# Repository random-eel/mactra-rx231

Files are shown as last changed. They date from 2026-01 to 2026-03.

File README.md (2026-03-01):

<p align="center">
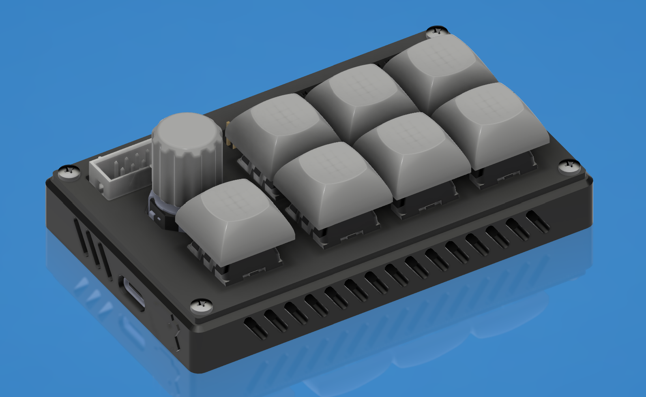
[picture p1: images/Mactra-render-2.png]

</p>  

# Mactra RX231搭載 エンコーダ付き7キーマクロパッド/開発ボード
Mactra はRenesas製RX231マイコンを搭載した、7キーマクロパッド 兼 開発ボードです。  
#### キーマップ変更は [こちらのサイト](https://random-eel.github.io/mactra-configurator/index.html)へ (要WebHID対応)  
設定ツール説明等は [こちら](https://github.com/random-eel/mactra-rx231/wiki)  
  
## 仕様・機能
 - Renesas製 RX231 マイクロコントローラ搭載 (R5F52315ADFL 48ピンQFP)
    - 32MHz 動作 (16MHz 外部発振器付き)
    - USB-C接続 (ファンクションのみ)
    - USBバスパワー動作専用
 - Kailh製MX互換スイッチホットスワップソケット x 7
   - ホットスワップなので好きな互換スイッチに入れ替え可能
   - RGB LEDバックライト付き (SK6812Mini-E Bit-bang制御)
   - 1 + 2行x3列 での接続
   - 2x3+ロータリーエンコーダ部分にダイオード有 (Col->Row)
 - RKJXT1F 4方向スイッチ付きロータリーエンコーダ x 1
 - 動作確認用オンボードLED x 2
 - GPIO/GND ピンソケット
 - 3.3v/5v ピンヘッダ
 - E2 エミュレータ用コネクタ

(ソフトウェア機能)
 - WebHIDを使用したコンフィグツール
	 - USB HIDを介したデータ転送
	 - RGB設定項目変更機能
	 - キー再配置機能
 - キー押しっぱなし機能
> [!WARNING]
> ### ⚠️ Rev.1はファームウェア書き込み時に特定のピンをショートさせる必要があります。ご注意下さい。
> Rev.2 も必要ですが、デバッグポート側にスイッチが存在し、ケーブル等で接続する必要はありません。

> [!CAUTION]
> ### ☠️ Rev.1はロータリーエンコーダの配線に致命的なミスがあり使用できません。  
> <b><u>メインボードだけRev.2の場合があります。</u></b>上記のスイッチで見分けてください。  

※~~現在ファームウェア開発中 開発状況を以下に示します。~~ 26/2/24 最低限の機能を実装したため、ファームウェア開発を完了しました。   
|開発状況|内容|説明|
|:---:|:---:|---:|
|✅️|Lチカ|背面LED点滅|
|✅️|[GPIOチェックファームの作製](https://github.com/random-eel/mactra-rx231/blob/main/firmwares/RX231-Mactra-GPIO-Test.mot)|ハンダ付けテスト用|
|✅️|[マトリクステスト](https://github.com/random-eel/mactra-rx231/blob/main/firmwares/RX231-Mactra-Matrix-Test.mot)|全キーのスキャン|
|✅️|ロータリーエンコーダ回転対応|左右回転方向等の取得|
|✅️|エンコーダ4方向スイッチ対応|上下左右のスイッチ|
|✅️|USBファンクション動作|USBデバイスとして認識|
|✅️|キーボード動作|マクロキーとして使用可能に|
|✅️|[RGB LED動作](https://github.com/random-eel/mactra-rx231/blob/main/firmwares/RX231-Mactra-SK6812Mini-E-Test.mot)|SK6812Mini-Eの点灯|
|✅️|RGB LED設定対応|キー同時押し等で変更|
|✅️|キーの設定変更対応|(ストレッチゴール)|  

## 使用方法
Mactra本体とホストデバイスをUSB-Cケーブルで接続します。  
背面のディップスイッチを操作する必要がある場合は、**必ずケーブルを抜いてから**操作して下さい。

### マクロキーとして使用する場合
**電源を切った状態**で、背面ディップスイッチを BOOT MODE: Off; USB BOOT: Off; に設定後、ケーブルを接続します。  
ファームウェアが書き込まれている場合、ケーブル接続後にマクロパッドとして動作します。  
書き込まれていない場合、下記の ***開発ボードとして使用する場合*** を参考に、ファームウェアを書き込んでください。  

初期設定のキーマップは以下の通りです。
```
(左右でボリューム)
    輝度アップ
前曲 再生/停止 次曲   [F22] [F23] [F24] 
    輝度ダウン

    [ミュート]      [Pause] [Alt+PrSc] [PrSc]
```

RGB LEDの点灯パターン・色変更等は、操作仕様が未確定なので未実装です。  
キーマップの変更は、現状ソースコードからのビルドのみとなり、未対応です。  
マルチプルエンドポイントを使用したシリアル通信で変更可能になる予定です。  

### 開発ボードとして使用する場合
<details>  
<summary>詳細</summary>  
   
基板上で<u>GPIOへのプルアップ抵抗の接続はありません</u>。  
内蔵プルアップ抵抗を利用して下さい。  
また、開発ボードとしてGPIOを使用する際には、基板上で接続されているピンも含まれているので、使用時には注意が必要です。  
基板上に接続があるピンは下記の通りです。  

|ピン|機能|説明|
|:---|---|---:|
|P14|LED|動作確認(Lチカ)用　背面|
|P16|VCC|(ブートローダモード指定用)****|
|P26|TXD|(E2デバッガ用送信)*|
|P27|RGB|RGB LED 通信用**|
|P30|RXD|(E2デバッガ用受信)*|
|P31|SW1|左下スイッチ ダイオード無し***|
|P42|RCW|ロータリーエンコーダ用 時計回り|
|P46|RCCW|ロータリーエンコーダ用 反時計回り|
|PA1|COL4|スイッチ用マトリクス 縦4|
|PA3|COL3|スイッチ用マトリクス 縦3|
|PA4|COL2|スイッチ用マトリクス 縦2|
|PA6|COL1|スイッチ用マトリクス 縦1|
|PE1|ROW3|スイッチ用マトリクス 横3|
|PE2|ROW2|スイッチ用マトリクス 横2|
|PE3|ROW1|スイッチ用マトリクス 横1|
|PE4|COL5|スイッチ用マトリクス 縦5|

\* シングルチップモード/FINED接続で使用する場合、自由に使うことが出来ます。  
** BSS138が接続されています。 常にRGB LEDに信号が流れるので、注意が必要です。  
*** スイッチはグラウンドと接続されています。  
**** USB経由でのファームウェア書き込み時に必要です。  
書き込み用スイッチ(横のスライドスイッチ)がオンのままGNDに接続しないで下さい。  

#### プログラムをUSB経由で書き込んで使う場合

> ##### ⚠️ Rev.1の場合
> スイッチを設定しても、ブートローダーモードへ起動せず、ファームウェアが書き込めません。  
> GPIO P16ピン と 3V3 ピンを接続してください。
> ##### ⚠️ Rev.2の場合
> 側面に P16-3V3 を接続するスイッチがあります。
> USB側にスライドするとOFFです。
 
<details>
<summary>詳細</summary>
 
1. **ケーブルを抜いた状態**で、背面ディップスイッチを BOOT MODE: On; USB BOOT: On; に設定後、ケーブルを接続します。  
2. Renesas Flash Programmer を使用して、ビルドしたプログラムを指定し、書き込みます。  
3. **ケーブルを抜き**、背面ディップスイッチを BOOT MODE: Off; USB BOOT: Off; に設定後、ケーブルを再接続します。
</details>

#### E2 エミュレータを使う場合(オンチップデバッギング)
<details>
<summary>詳細</summary>
 
1. **電源を切った状態**で、背面ディップスイッチを BOOT MODE: **Off**; USB BOOT: **Off**; に設定します。
2. **電源を切った状態**で、E2エミュレータとキーボードを接続します。  
3. CS+/e2studio で E2エミュレータの設定をし、接続します。 (エミュレータから電源供給可 - LED使用時は注意)
4. プログラムを実行します。  
※ E2エミュレータから電源を供給すると、5V端子の出力は無効化されます。  
※ E2エミュレータから電源を供給しても、RGB LEDにも3.3v電源が供給されます。供給電流を超えないように明るさを調整して下さい。  
</details>

> ##### ⚠️ Rev.1 & 2の場合
> GPIO P16ピン と GND ピンを接続しないでください。  
> 電源がショートし、最悪破損します。  

</details>  

## ケースについて
> [!IMPORTANT]
> 26/3/1 時点でファイルが更新されておりません。 今暫くお待ち下さい。
  
casesフォルダに3Dプリンタで出力可能なモデルを用意してあります。  
以下のネジが必要になります。何れもセルフタップになります。  
 - 3Dプリントしたケースの場合 (Type 1: 中間+キーカバー)
   - M2 15mmネジ x 4
 - 3Dプリントしたケースの場合 (Type 2: 中間のみ)
    - M2 5mmネジ x 8
 - ケース無しで使う場合 (GPIO使用時には注意)
    - M2 5mmネジ x 8
    - M2 10mm スタンドオフ x4
  
## ソースコードについて (TBD)
Renesas製のサンプルコード及びFITモジュールを使用しているため、公開可能かどうか不明です。(もう少し調べます...)  
  
御連絡頂ければソースコードをお送り致しますが、最低でもルネサスのアカウントを取得してください。    
(使用したコード・モジュール全てが、ルネサスのアカウントさえあればダウンロード可能な為)  
  
> [!WARNING]
> #### ⚠️ AI生成コードについて
> このキーボードのファームウェア開発にはGeminiを使用し生成したコードが含まれています。ご了承下さい。  
> 自作/生成したコードのみで動作するファームウェアが完成した場合、確認後にすべてのソースコードを公開する予定です。  
  
## 使用したアプリ・参考にしたサイト・サンプルコード等
* KiCAD 9.0.6
* Autodesk Fusion 360
* [Keyboard Layout Editor](https://www.keyboard-layout-editor.com/)
* [ai03 Plate Generator](https://kbplate.ai03.com/)
* [秋月電子 RX621マイコンボード 参考資料(回路図)](https://akizukidenshi.com/catalog/g/g105763/)
* [RSK-RX231 RX231 CPU Board Schematics](https://www.renesas.com/ja/design-resources/boards-kits/rsk-rx231)  
* [RX230, RX231 ハンドブック](https://www.renesas.com/ja/products/rx231)
* [RX230グループ、RX231グループ　ユーザーズマニュアル　ハードウェア編](https://www.renesas.com/ja/products/rx231)
* [RXファミリ ハードウェアデザインガイド](https://www.renesas.com/ja/products/microcontrollers-microprocessors/rx-32-bit-performance-efficiency-mcus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)
* [メインクロック回路、サブクロック回路のデザインガイド](https://www.renesas.com/ja/products/microcontrollers-microprocessors/rx-32-bit-performance-efficiency-mcus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)
* [Hardware design with RP2040](https://www.raspberrypi.com/documentation/microcontrollers/pico-series.html#documentation)
* [USB.org HID Usage Descrptions](https://usb.org/sites/default/files/hut1_21.pdf)
* RX Family Sample Program using USB Host Human Interface Device Class Driver (HHID) to communicate via USB with HID device Firmware Integration Technology Rev.1.30 - Sample Code (r01an2294)
* [tmk_keyboard](https://github.com/tmk/tmk_keyboard)
* [TinyUSB](https://github.com/hathach/tinyusb)
* [dsa-keycap](https://github.com/anhthang/dsa-keycap)
* ポリテクセンターの講義・資料
* Google Gemini

## FAQ
### 動作しない
電源LEDが点灯しない場合は、故障だと思われます。  
点灯していても動作しない場合は、ディップスイッチの設定を確認して下さい。  
ファームウェアが書き込まれていない可能性もありますので、RFSを使用して書き込んで下さい。  
開発ボードとして使用している場合、動作させているコードに問題がある可能性があります。(in short: you suck at coding)  
### RGB LEDの設定を変更したい
ロータリーエンコーダを押し込みながらSW1(ロータリーエンコーダ下スイッチ)を押すと、設定変更モードになります。  
上下で設定項目の変更、回転で数値を変更します。    
LEDが黄色の状態で左右を入力すると、LEDの点灯モードが変更できます。
|色|機能|
|---|---|
|黄|輝度変更|
|赤緑青|色彩変更|
|赤緑青/白|色彩2変更|
|紫|(未実装)|
|水|LED更新速度|
  
### スマホからキーマップ変更出来ない  
現状WebHIDのサポートが無いようです。(Android/iPhone)  
設定変更にはPCを使用して下さい。  
### キーボードのリセットを行いたい
ロータリーエンコーダを押し込みながらSW1(ロータリーエンコーダ下スイッチ)を押したまま、USBケーブルを繋げて下さい。  
それでもリセットされない場合、エンコーダ押し込み+上部のキー全てを押しながら、ケーブルを繋げて下さい。  
### 基板から注文したい
手動でのはんだ付けが幾つか必要になります。某◯月電子からMCU・ピンヘッダ・ソケット等の購入で価格を抑えられます。  
RKJXT1Fは、AliExpressから購入すると良いかもしれません。  
PCBAをするならJLCPCBをおすすめします。代替・未実装の部品を指定すると価格を抑えられます。 (not affiliated!)  
スイッチ・キーキャップ含め 5枚で2万円程になると思います。(25/1/16)  
### なぜ製作に至ったのか 
職業訓練校で使い方を学んだRXシリーズを使用して、自身のスキルを試し、能力を証明してみたかった点が一番の理由です。  
RXシリーズの開発ボードを勉強目的で安価に手に入れたかったのですが、普通の物では面白くないと思い、制作に至りました。
  
## 免責事項
このデバイス 及び ファームウェアを使用していて、誤字が増えた、ホストデバイスが壊れた、核戦争が起きた、デバイスが正しく動作しなかったせいで会社をクビになった等があっても、設計/製作者は一切の責任を負いません。  
  
## その他
 
<details>
  <summary>読まなくてもいい詳細</summary>
  
<details>
  <summary>本当に読むんですか？ (どうでもいい事しか書いてないです) </summary>

<details>
  <summary>本当の本当に読むんですか？ (実質知り合い向けな上、色々と遠慮しておりません) </summary>

<details>
  <summary>本当の本当の本当に読むんですか？ (NOT WORTH READING THIS (mostly), YOU HAVE BEEN WARNED) </summary>
  
### なんてよむの  
"[マクトラ](https://www.google.com/search?q=mactra)" です。~~このバカ貝め~~
### QMKは?
MCUのサポートが無いので無理です。どなたかがChibiOSを移植して貰えれば出来るんじゃないですかね？  
### 他のファームウェアは？
( ◠‿◠ ) 回路図あるんだから自分で用意しろ！  
### 他のMCUで作る予定は？
( ◠‿◠ ) 無い。（多分… ルネサスのチップを載せたくなったら作ります）  
### でも他のMCUの方が安いし楽なのでは?
RXシリーズの勉強用なので、それでは意味が無かったんです。  
### 勉強に使える開発ボードにしてはBYTEでアクセスしづらくない？  
安く手に入るチップがこれだったので仕方がありませんでした。  
もし次にルネサス製のチップを使うならRAにします。  
### 設定用データのパケットの内容は？
設定ツールを見て下さい。(そのうち説明は追加します)  
### 回路図は？  
~~そのうち追加予定です。~~ 26/1/26: 追加しました。[docs/mactra-schematics-rev2.pdf](https://github.com/random-eel/mactra-rx231/blob/main/docs/mactra-schematics-rev2.pdf) 
### 基板データは？
いずれ追加予定です。（Rev.2も思った通りの動作ではない為未定ですが、近日追加します)   
### BOMは？
同梱予定です。少量の位置確認が必要だと思われます。  
スイッチソケット・ダイオードアレイ・TVSダイオード・USBコネクタの位置確認が必要です。  
### アナログ入出力ヤバいんだけど  
ルネサスのデザインリファレンス通りでは無いのであしからず。おまけだと思ってもらえると。  
### LED邪魔  
電源LEDなら諦めて下さい。(自分で抵抗入れ替えるか外せば消えます)  
P14のLEDは光らないはずです。RGBバックライトはオフに出来るようにします。  
### テストファームの使い方は？
手ハンダでMCUを実装したときに、正しくハンダされているかのチェックに有用です。  
GPIO全て(P14除く)がプルアップ抵抗有効の入力ピン設定になります。  
全てのGPIOに順番に GPIOn-GND のように接続し、背面LEDが点灯することを確認して下さい。  
### なんでRev.1/2はショートが必要？
P16ピンが5V/3.3V/HIGHでなければ、USBブートモードへ移行しないようです。  
P35はVCCとの接続がありますが、どうやらブートローダのモード設定には使えないようです。ぴえん。  
使用にはあまり問題は無いと思われます(ファームウェアではP35がUSB0_VBUS設定)が、留意して使用して下さい。 
### 普通にP16潰せば良いのでは？
RIICの割り当てがあります。
### Rev.2スイッチ切ってもP16使えないんだけど？
(説明TBD) 配線もしくはスイッチの選択をミスったようです。オフの状態でも多少電流が流れてしまっているようです。  
スイッチのグラウンド不良の可能性がありますが、不明です。(シールド実測で0.3v程 スイッチのNCを真に受けた為?)  
### 配線汚いし間違ってるとかアホ？
( ◠‿◠ ) うるせえ 初心者なんだよ 誰もが通る道なんだよ
### AI使うとか雑魚？
雑魚です。正直かなり助かりました。特にUSB周りはヘルプ無しでは無理だったと思います。  
### FAQ舐めてんの？
仲間・友人程度しか見ないだろうと踏んでおります。  
あくまで勉強のための趣味の品だと思って頂けると幸いです。  
こんな素人の作品に本気になってどーすんのｗ   
### 設計者は何奴？
よくわからん少しキーボード好きの人間です。普段はRP2040で制作しています。どうでもいいですが求職中です。(26/3/1)
</details>
</details>
</details>
</details>

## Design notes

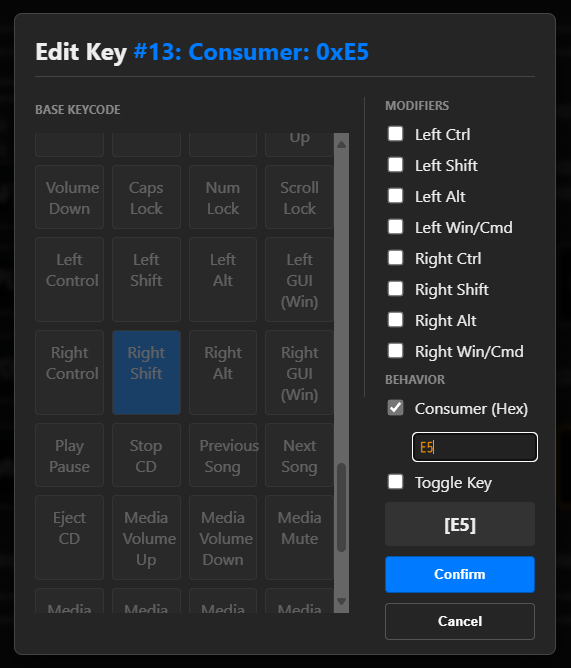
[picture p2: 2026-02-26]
images/customizer-image-consumer-0.png

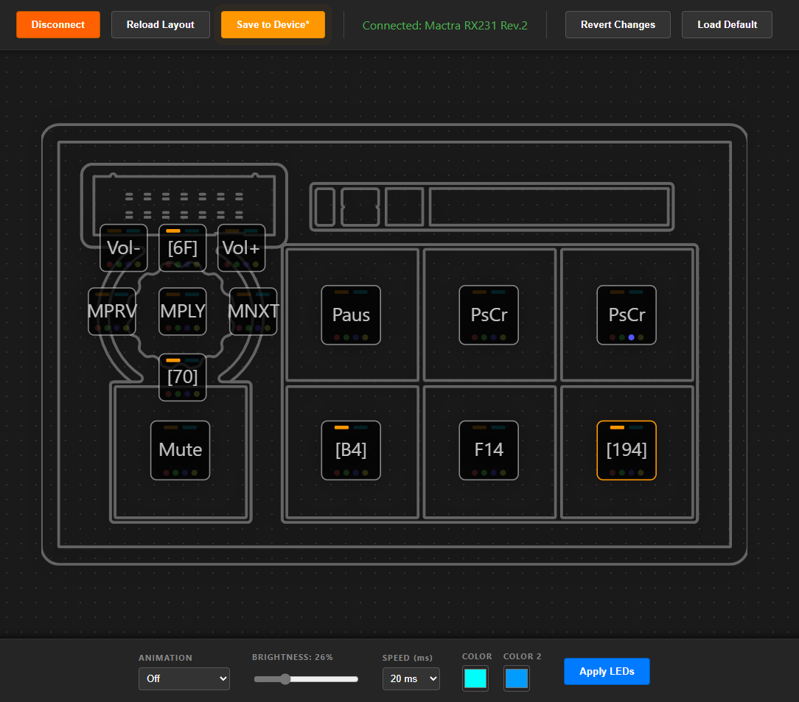
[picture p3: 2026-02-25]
images/customizer-image-0.png

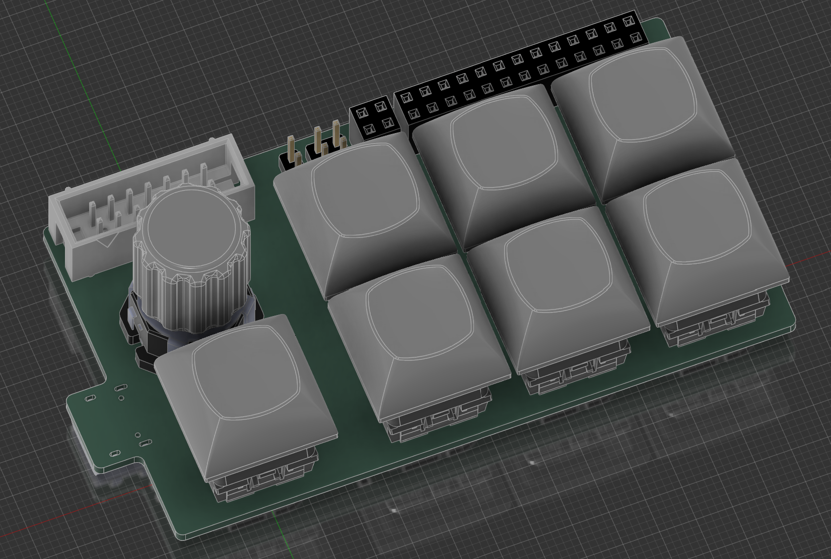
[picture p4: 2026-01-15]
images/mactra_preview.png

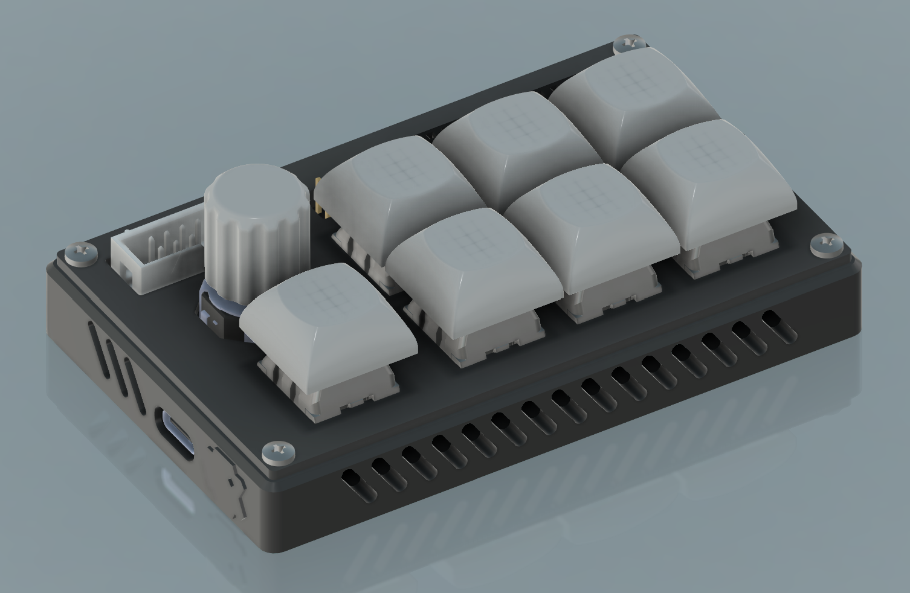
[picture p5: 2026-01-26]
images/Mactra-render.png

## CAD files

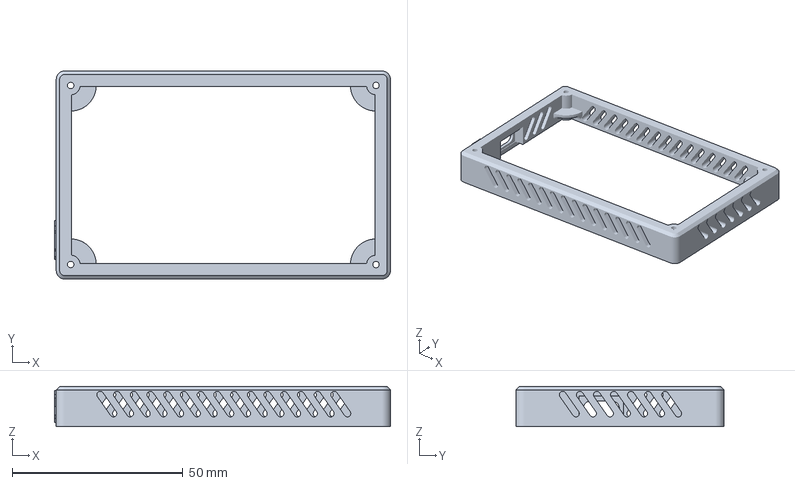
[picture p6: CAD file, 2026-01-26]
cases/Mactra-R1-Skelton-NoTop.3mf
98.5 x 61.0 x 11.8 mm

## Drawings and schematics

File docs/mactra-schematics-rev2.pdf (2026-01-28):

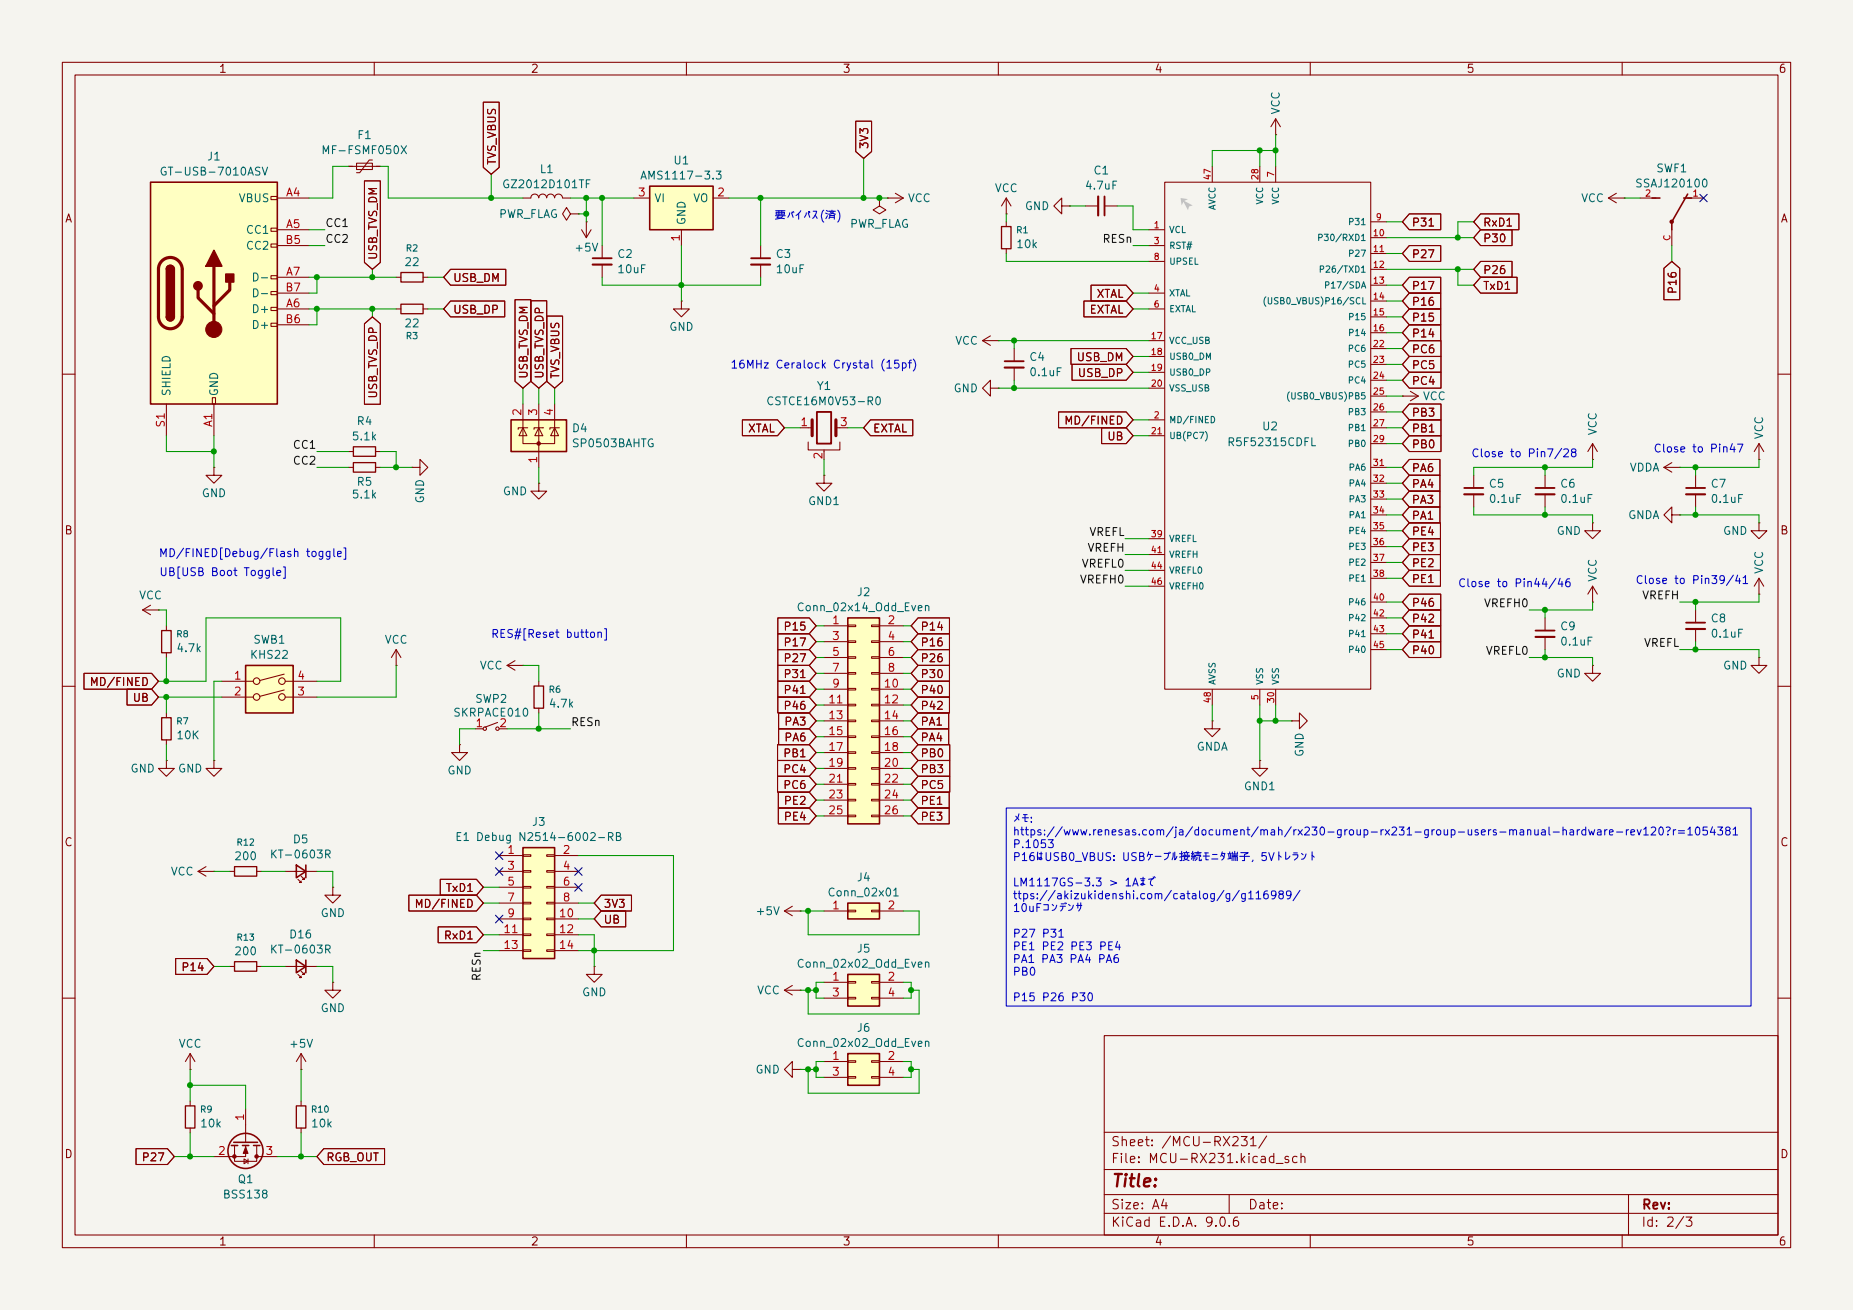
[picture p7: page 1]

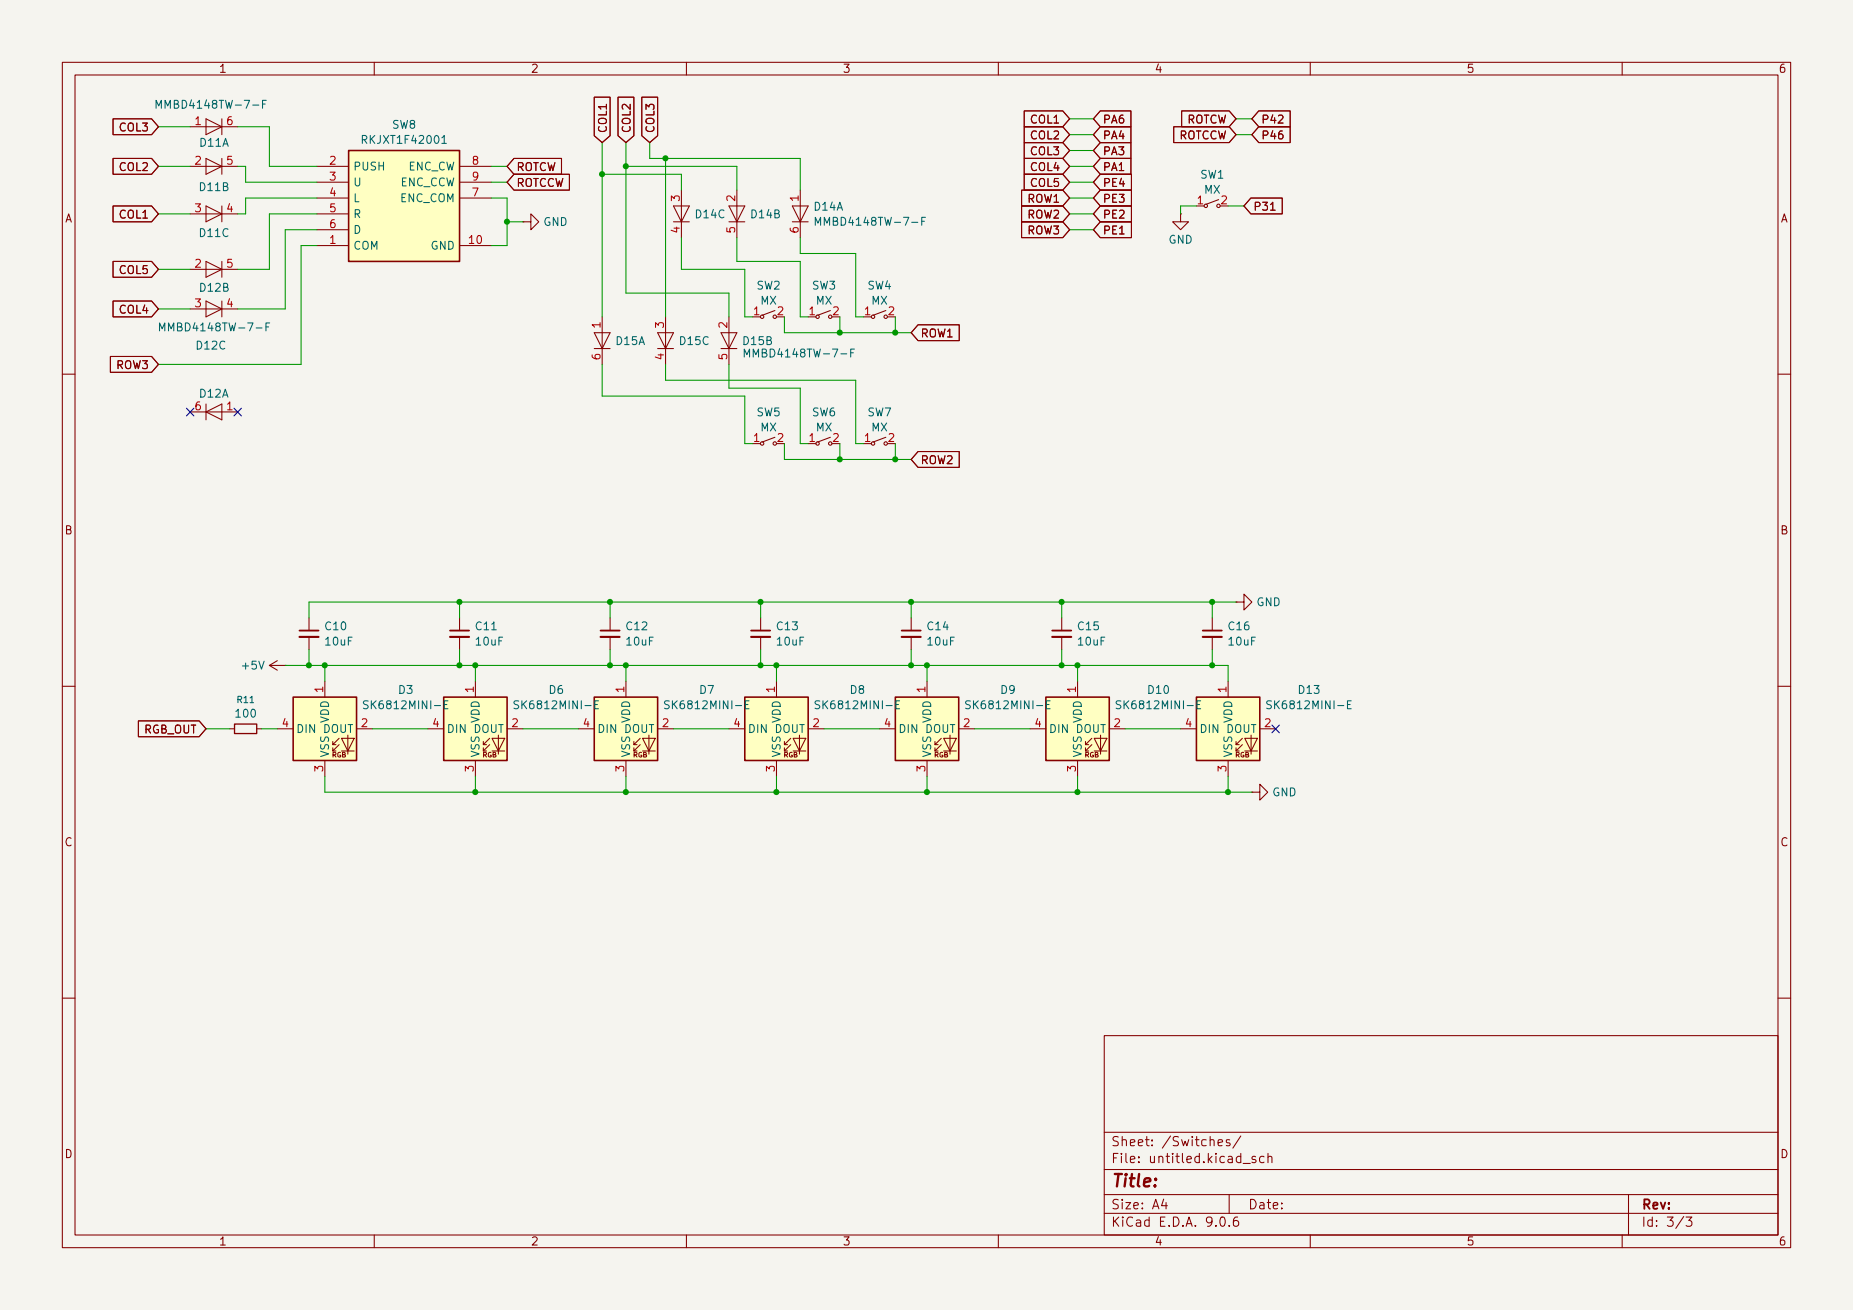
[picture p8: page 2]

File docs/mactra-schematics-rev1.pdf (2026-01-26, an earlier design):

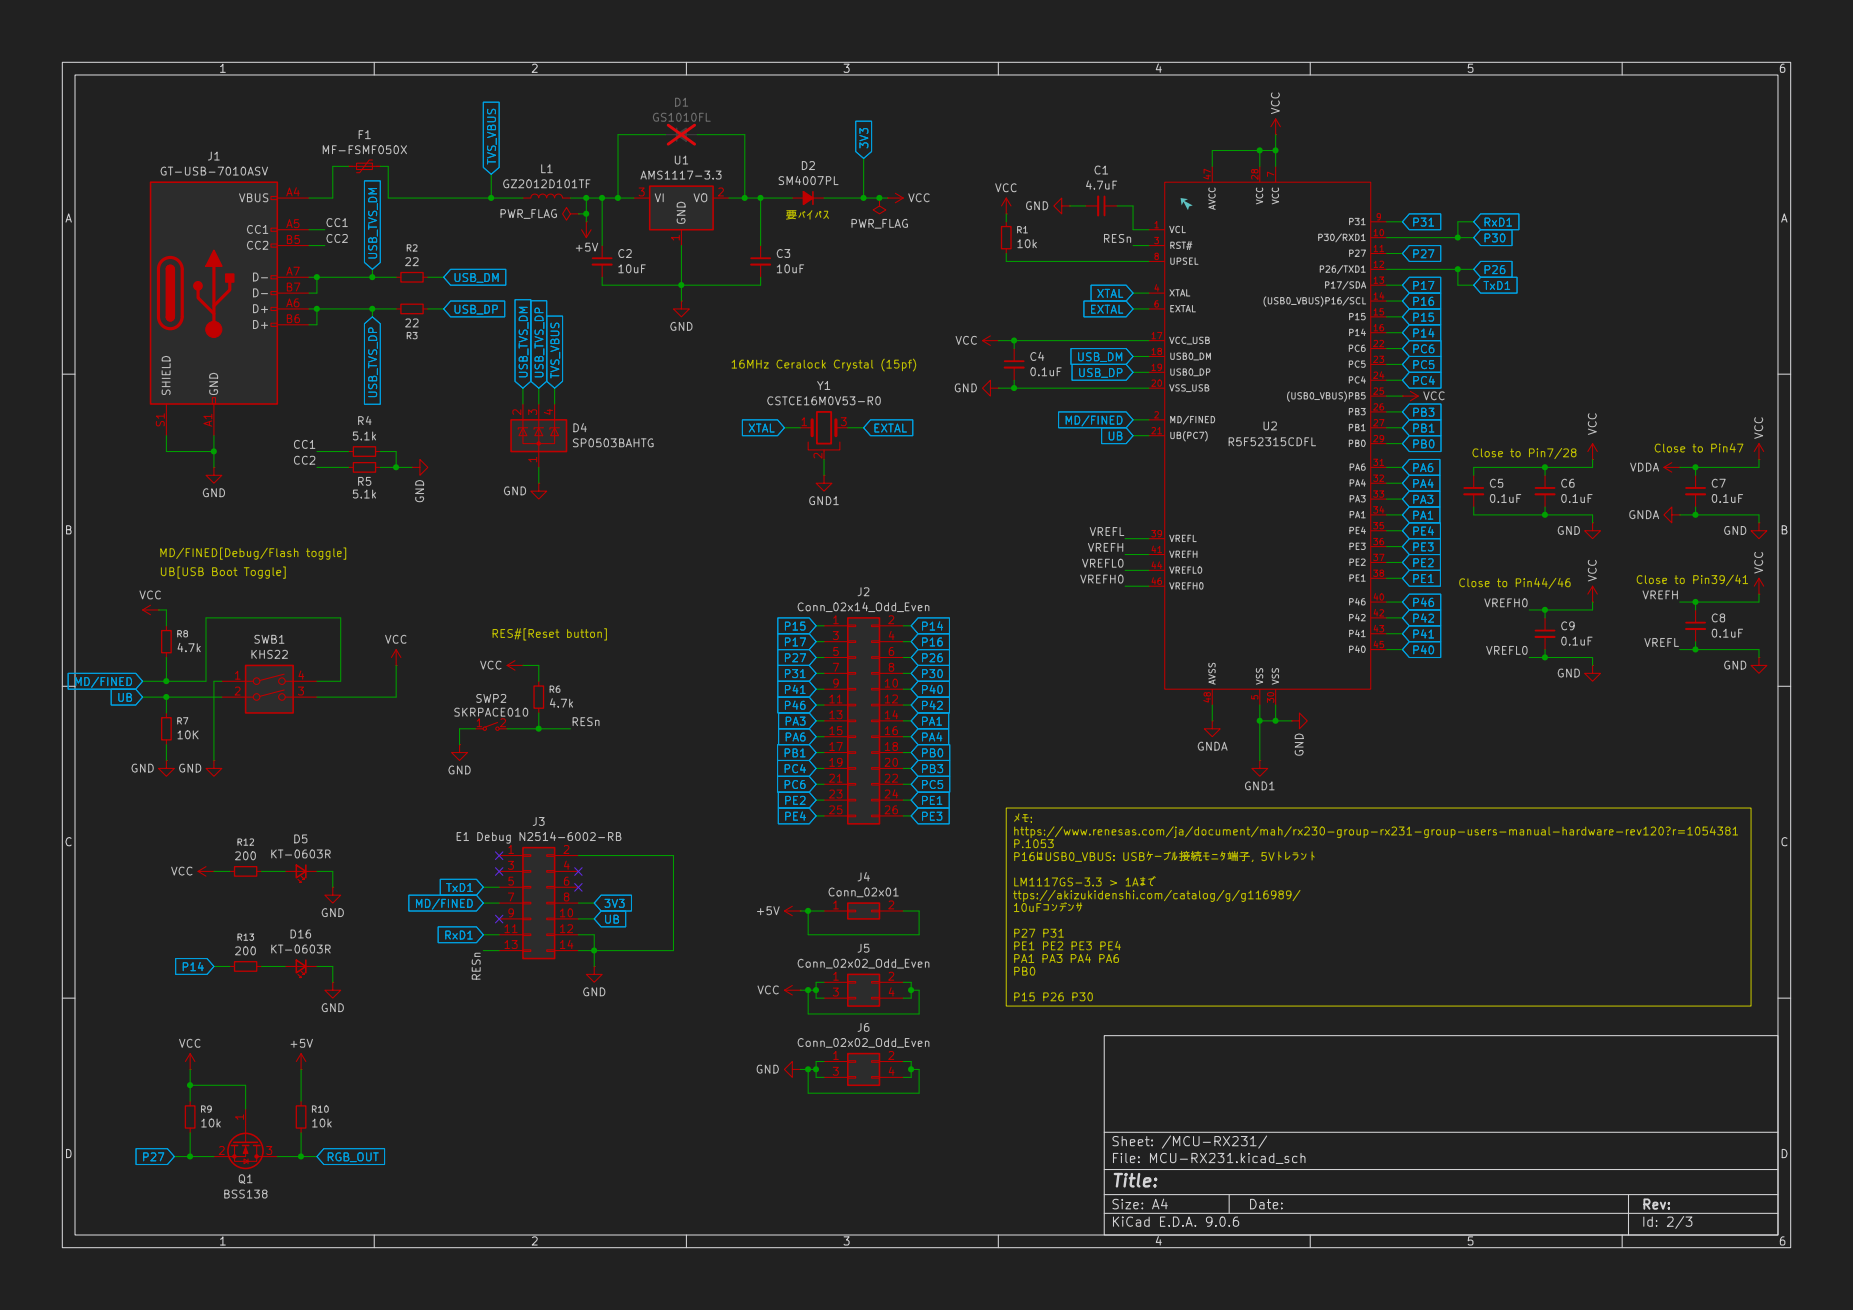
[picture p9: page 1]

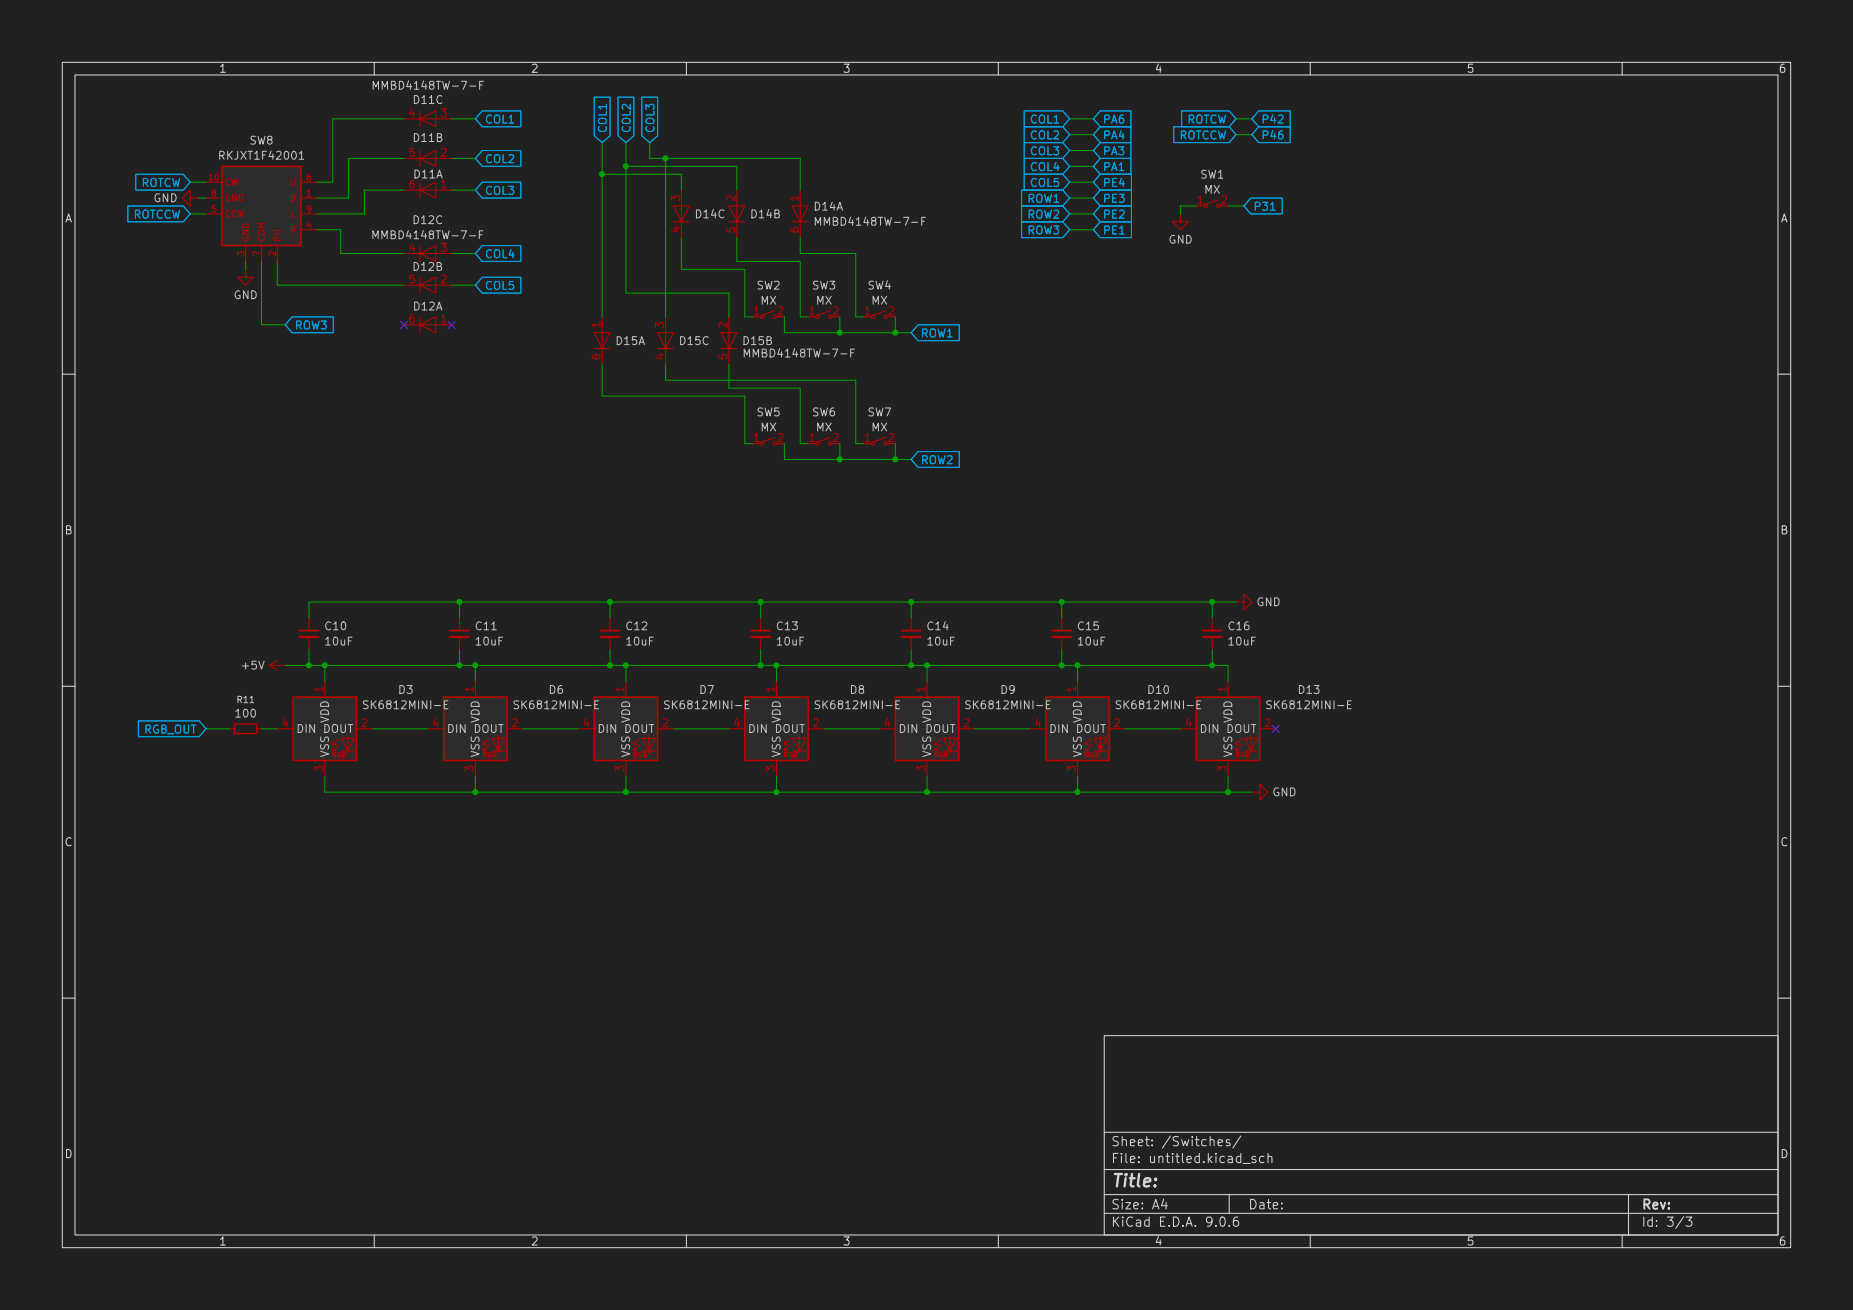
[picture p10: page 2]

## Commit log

2026-01-15 Update README.md
    説明を追加
2026-01-15 Update README.md
    ケースが必要な際の部品リスト追加
2026-01-15 Update README.md
    キーマップ・ケースに必要な部品等の追加
2026-01-15 Create folder
    Where's the damn "create direcotry" button, github?????????
2026-01-15 Update README.md
    画像の追加
2026-01-16 Update README.md
    内部接続ピンとFAQを追加
2026-01-21 Update README.md
    ファーム開発進捗追加
    エラッタ情報追加
2026-01-26 Update README.md
    色々追加
2026-01-26 Update README.md
    もう少し説明追加
2026-01-26 Add schematics
    回路図PDFのアップロード
2026-01-26 Add test firmware and case
    Initial firm/case upload
    [Mactra-R1-Skelton-NoTop.3mf]
2026-01-26 Update README.md
    画像差し替え・ファームウェア追加
2026-01-27 Add files via upload
    SK6812Mini-E テスト用ファームウェア追加
2026-01-27 Update README.md
    Rev.1注意書き追加
    進捗更新
2026-01-28 Rename mactra-schematics.pdf
    to mactra-schematics-rev1.pdf
2026-01-28 Add files via upload
    Rev.2 schematics
2026-02-01 Update README.md
    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
2026-02-08 Add matrix test firmware
    マトリクステスト用ファームウェア追加
2026-02-11 Update README.md
    色々更新
    使用したリソースを追加
2026-02-11 Add alpha firmware
    Add working macropad firmware without LED control and EEPROM support.
2026-02-20 Update README.md
    キーマップ変更アプリへのリンク追加
    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
2026-02-20 Add release firmware
    一通り動作するファームウェア追加
2026-02-25 Update README.md
    ソース/FAQ等追加
2026-03-01 Update README.md
    最新の情報・FAQ・順番等変更
